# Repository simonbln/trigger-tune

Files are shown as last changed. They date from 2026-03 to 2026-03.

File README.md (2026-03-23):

# trigger-tune
Open-source audio player triggered by light beams

## Table of Contents
## Table of Contents
1. [Components](#components)
2. [Wiring Diagram](#wiring-diagram)
3. [Firmware Details](#firmware-details)
4. [DFPlayer Mini & SD Card Setup](#dfplayer-mini--sd-card-setup)
5. [LED Status Indicators](#led-status-indicators)
6. [How-To](#how-to)
    - [Breadboard Prototyping](#breadboard-prototyping)
    - [Firmware Setup](#firmware-setup)
    - [Important: USB Power Handling](#important-usb-power-handling)
    - [Build Prototype](#build-prototype)
7. [Support me](#support-me)
8. [Third-Party Code and License](#third-party-code-and-license)

## Components
- RP2040 (Zero)
- DFPlayer Mini
- USB Connector
- WS2812 (NeoPixel LED)
- Audio Jack
- Micro SD Card
- Perfboard (5x7cm)
- Connectors / Cables
- Enclosure / Box
- Lightbeam normally open NPN (if other is available, you have to adjust the code. Create a Issue if you have problems here)

## Wiring Diagram
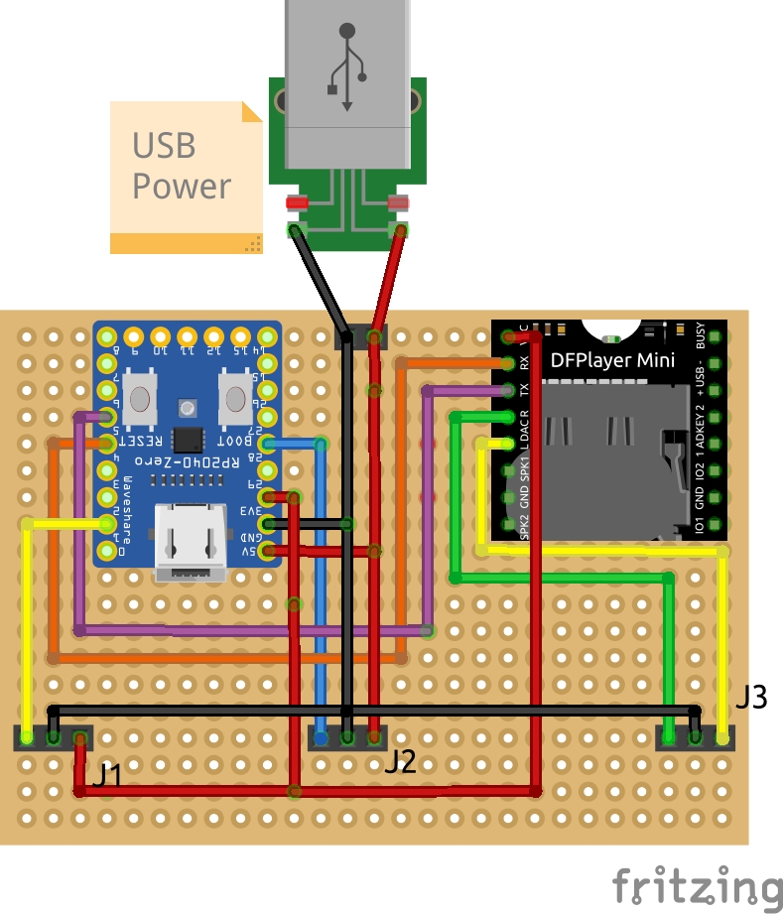
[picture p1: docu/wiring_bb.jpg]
Wiring Diagram

Figure 1: Wiring diagram on the perfboard

- **Connector J1** connects to the light barrier; the wiring will be split later into transmitter and receiver units. Additional light barriers can be wired in parallel here.
- **Connector J2** connects to the external WS2812 LED.
- **Connector J3** connects to the audio jack.

## Firmware Details
The firmware is written in **MicroPython** and utilizes a modified version of the [penguintutor/dfplayermini-pico](https://github.com/penguintutor/dfplayermini-pico) library.

The program continuously **polls the GPIO pin** connected to the light barrier. When triggered, it selects and plays a random MP3 file from the SD card. To ensure variety, the logic includes a mechanism that prevents the same track from being played twice in a row.

### Power Management & Optimization
While the RP2040 supports **Deep Sleep** with GPIO interrupts, this was not implemented. The **DFPlayer Mini** remains the primary power consumer in the circuit, making the power savings from MCU sleep modes negligible for this specific application.

## DFPlayer Mini & SD Card Setup
The DFPlayer Mini requires the SD card to be formatted to **FAT16 or FAT32**.

### SD Card Structure
The module requires a specific file naming convention to function reliably:
- **Folder naming:** Use a folder named `01` in the root directory.
- **File naming:** Files should be prefixed with a three-digit number (e.g., `001.mp3`).

## LED Status Indicators
The WS2812 LED (internal on PIN 16 and (optional) extenal on PIN 28) provides visual feedback on the system's state:

- **White:** System is initializing.
- **Green:** Ready and waiting for light beam trigger.
- **Blue:** Triggered / Playing audio. The LED stays blue for 1 second upon trigger; the song continues to play until the end unless a new trigger occurs during playback.
- **Red:** Error. No SD card detected or no MP3 files found in the specified folder.
- **Yellow:** Obstruction warning. The light beam is being triggered continuously (likely blocked or misaligned).

## How-To

### Breadboard Prototyping
For initial testing, it is recommended to build the circuit on a breadboard first as seen on the wiring diagram.

### Firmware Setup
1. Install **Thonny** IDE on your computer.
2. Flash the **MicroPython firmware** to the RP2040.  
   > **Firmware download:** [MicroPython for RP2040](https://micropython.org/download/rp2-pico/)
3. Copy all files from the `firmware` folder to the RP2040.

### Important: USB Power Handling
- **Do not** connect an external USB power source to the additional USB port while the RP2040 is connected to your computer via USB.
- Once the RP2040 is disconnected from the computer, the external USB port can be used to power all components. But for testing purpose you can use the USB Port of the RP2040.
- The external USB port will later be integrated into the enclosure.

### Build prototype
Solder the components and wires onto the perfboard as shown in Figure 1. Once the assembly is complete, perform an initial functional test before mounting the board into the enclosure.

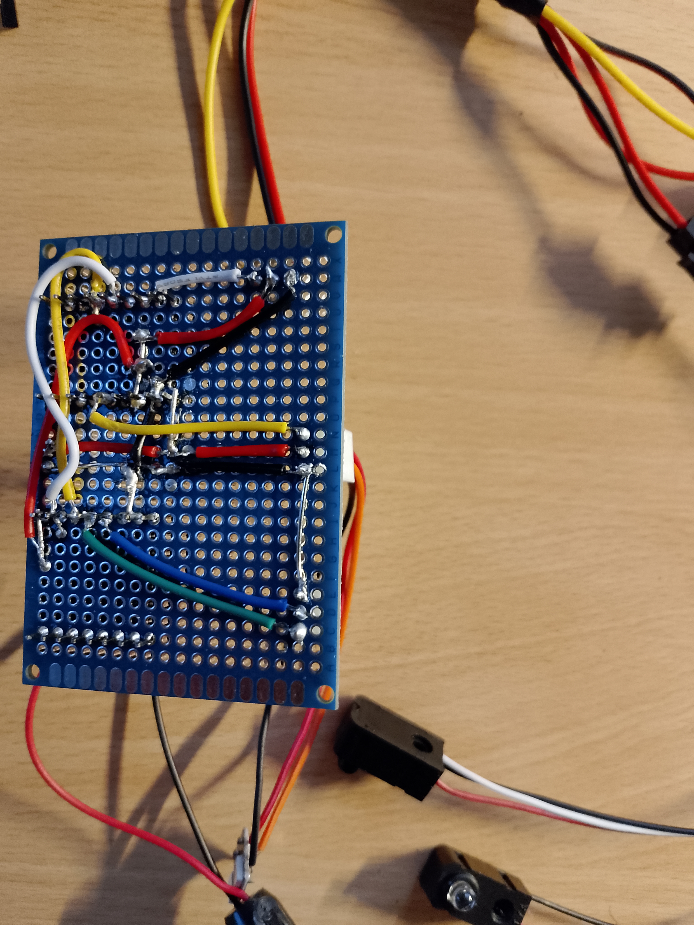
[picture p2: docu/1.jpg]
Soldering

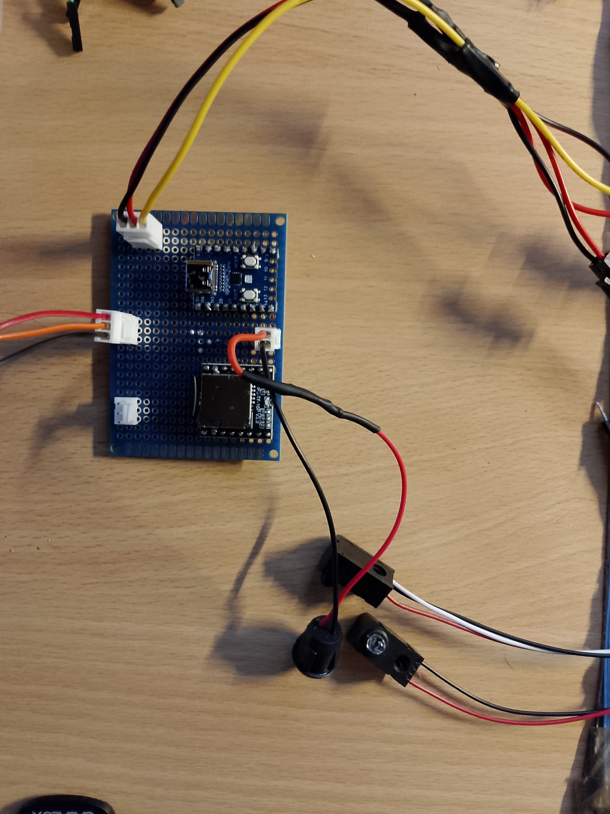
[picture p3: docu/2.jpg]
First Test


I decided to mount the circuit board to the lid. Since the enclosure is designed to be screwed down from the bottom, this prevents the mounting screws from interfering with the electronics. However, the board can also be mounted inside the box itself if preferred. I used rubber washers to dampen expected vibrations and minimize their transfer to the PCB.

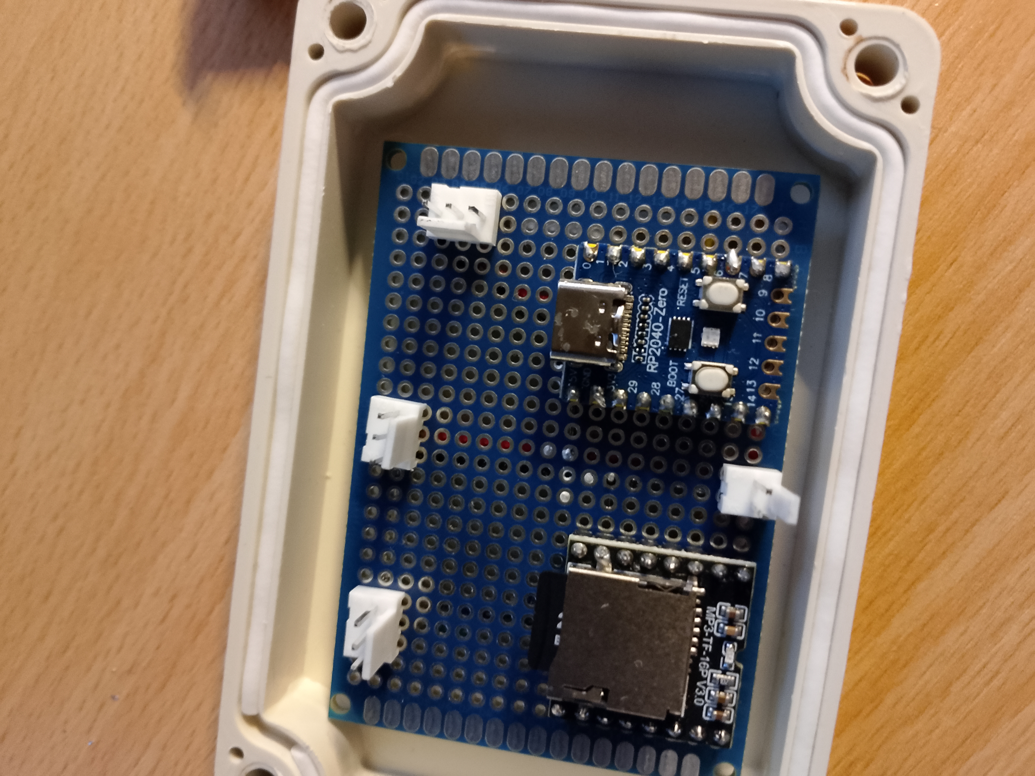
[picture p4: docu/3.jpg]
PCB in the lid


Drill the necessary holes for the cable glands and connectors, then insert them and secure with hot glue if necessary. The status LED was also routed through the lid for better visibility.

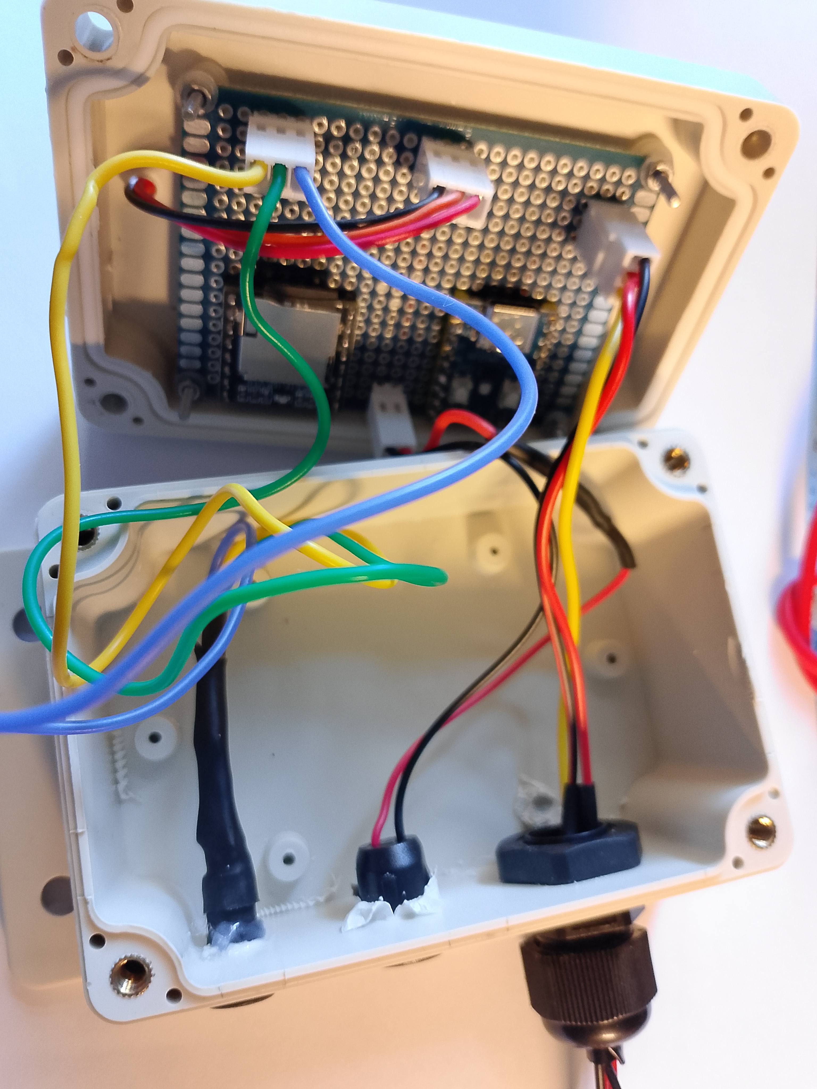
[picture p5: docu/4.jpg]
in the enclosure 1

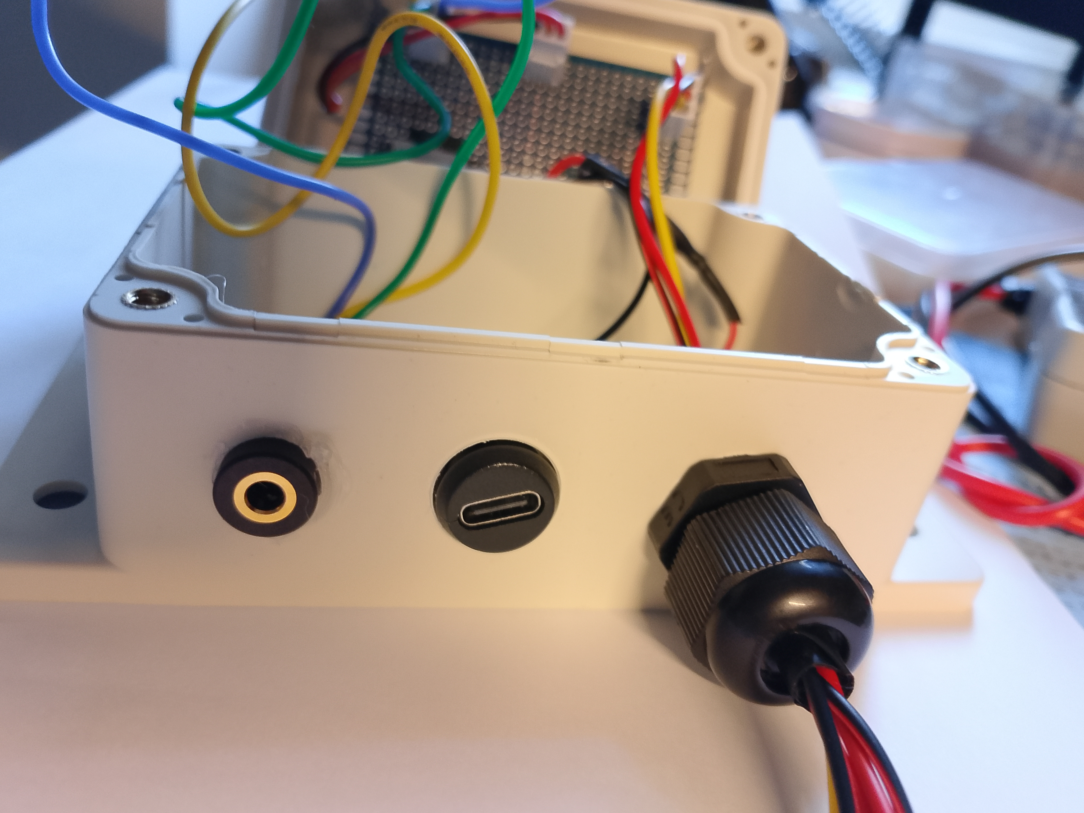
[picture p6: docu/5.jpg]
in the enclosure 2

PCB in the lid

**Note**: I am using two light barriers in this setup. Therefore, the wiring is split to connect both pairs (two transmitters and two receivers) in parallel.

## Support me
If you find this project helpful and would like to support my work, I would be very grateful for a contribution via GitHub Sponsors or in Bitcoin (BTC) / Litecoin (LTC). Every bit of support helps me to keep creating and sharing new projects. Thank you!

### LTC:
ltc1qx2yf4cndqr2zf3vfd7l2ywm5hylvhm0a8jrxry

LTC QR Code

### BTC: 
bc1q5yga8eluxk7cn4pc7k36lwee06mwt5gtre8nrm

BTC QR Code

### Bitcoin Cash
bitcoincash:qp4gapsmpt75nh7clp64dhae2myhl9h8tg2f77w652

Bitcoin_Cash QR Code

## Third-Party Code and License

This project contains modified code from the [penguintutor/dfplayermini-pico](https://github.com/penguintutor/dfplayermini-pico) repository.

*   **Original Author:** [@PenguinTutor](https://www.penguintutor.com)
*   **Original Repository License:** **GNU General Public License v3.0** (GPL-3.0) – see full text in the original repository's `LICENSE` file.
*   **Modifications by:** ([@simonbln](https://github.com/simonbln))
*   **Date of modifications:** March 2026
*   **Nature of modifications:**
    1.  Updated `command.to_bytes(1)` to `command.to_bytes(1, 'big')` for compatibility with newer Python versions.
    2.  Fixed the return value parsing for the reset command to correctly handle the module's response.

This modified version is distributed under the same license terms (GPL-3.0). The complete license text is included in this repository as `LICENSE`.

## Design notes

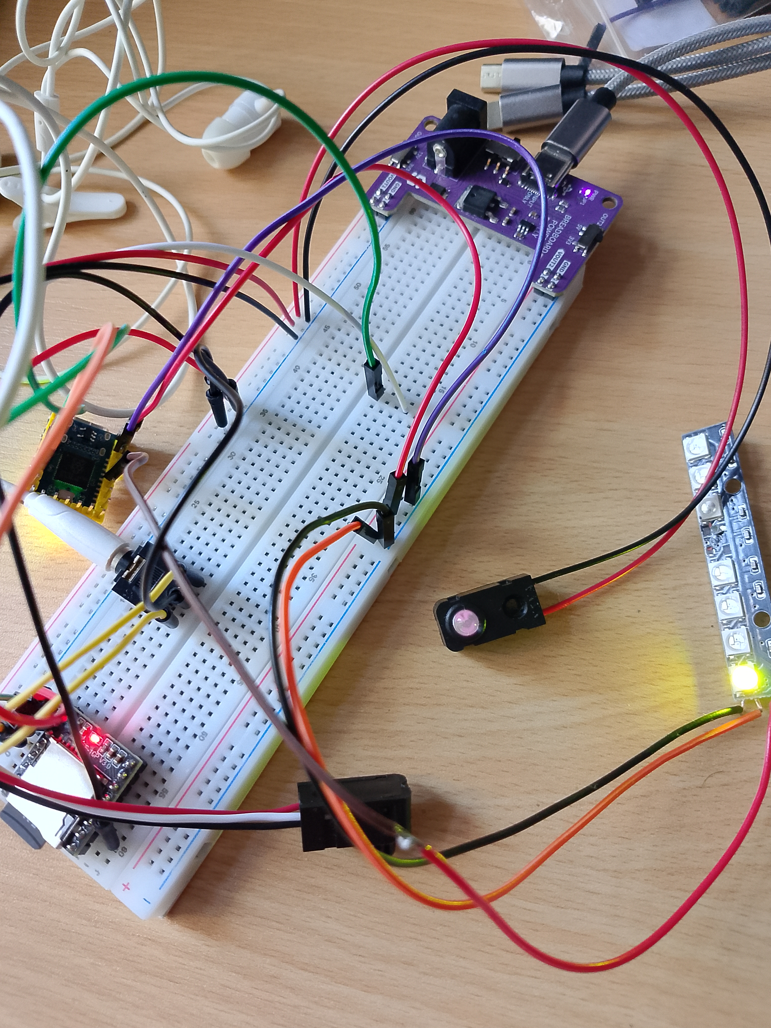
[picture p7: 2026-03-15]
docu/breadboard.jpg

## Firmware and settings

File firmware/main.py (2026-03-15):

from machine import Pin, UART, lightsleep
import neopixel
import time
import random
from dfplayermini import DFPlayerMini


print("start")


input_signal = Pin(2, Pin.IN, Pin.PULL_UP) 
pixel = neopixel.NeoPixel(Pin(16), 1)
pixel2 = neopixel.NeoPixel(Pin(28), 1)

class Colors:
    RED     = (50, 0, 0)
    GREEN   = (0, 50, 0)
    BLUE    = (0, 0, 50)
    YELLOW  = (50, 50, 0)
    CYAN    = (0, 50, 50)
    MAGENTA = (50, 0, 50)
    WHITE   = (50, 50, 50)
    OFF     = (0, 0, 0)

def set_pixel_color(color_rgb):
    pixel[0] = color_rgb
    pixel2[0]= color_rgb
    pixel.write()
    pixel2.write()
    
set_pixel_color(Colors.WHITE)

time.sleep(1)
player = DFPlayerMini(1,4,5)
time.sleep(1)
while True:
    print ("Reset")
    if player.reset() == True:
        print ("Reset: OK")
        break
    time.sleep(1)

time.sleep(1)
player.select_source('sdcard')

print ("Read Num files")
count_songs = player.query_num_files()
print (f"Num files {count_songs}")

print ("Read volume")
read_value = player.get_volume()
print (f"Volume {read_value}")

player.set_volume(30)

print ("Read volume")
read_value = player.get_volume()
print (f"Volume {read_value}")

ready_for_detection = True

last_song = 0

def play_random():
    global last_song
    if count_songs > 0:
        if count_songs == 1:
            # If only one song exists, just play it
            random_song = 1
        else:
            # Pick a song, but not the same as the last one
            random_song = last_song
            while random_song == last_song:
                random_song = random.randint(1, count_songs)
        
        # Update last_song for next time
        last_song = random_song
        
        print(f"Action: Playing random track {random_song}")
        player.play(random_song)
    else:
        print("Error: No songs found on SD card.")
        set_pixel_color(Colors.RED)

while True:
    if count_songs == 0:
        set_pixel_color(Colors.RED)
        time.sleep(2)
    elif input_signal.value() == 0:
        if ready_for_detection:
            ready_for_detection = False
            set_pixel_color(Colors.BLUE)
            play_random()
            time.sleep(1)
        else:
            set_pixel_color(Colors.YELLOW)
            time.sleep(0.5)
    else:
        ready_for_detection = True
        set_pixel_color(Colors.GREEN)
    time.sleep(0.05)

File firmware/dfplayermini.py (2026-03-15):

# A library to control the DFPlayer MP3 player
# Only partial implementation
# For more details of protocol see https://www.dfrobot.com/
# Created by Stewart Watkiss @PenguinTutor
# https://www.penguintutor.com 



# Original code by Stewart Watkiss @PenguinTutor
# https://www.penguintutor.com
# Source: https://github.com/penguintutor/dfplayermini-pico
# License: GNU General Public License v3.0 (GPL-3.0)
#
# Modified by simonbln - March 2026
# Changes:
# - command.to_bytes(1) -> command.to_bytes(1, 'big') for compatibility with newer Python versions
# - Fixed reset command return value parsing


from machine import UART, Pin
import time

class DFPlayerMini ():
    
    # how long to pause between read and write / subsequent reads
    sleep_time = 0.2
    debug = False
    
    sources = {
        'usb': 1,
        'sdcard': 2,
        'sd': 2,         # Allow sd as well as sd card
        'aux': 3,
        'sleep': 4,
        'flash': 5
        }
    
    def __init__ (self, uart_no, tx, rx):
        self.uart = UART(uart_no, baudrate=9600, tx=Pin(tx), rx=Pin(rx))
        self.uart.init(9600, bits=8, parity=None, stop=1)
        # Set to source when configured
        self.source = None
        # Keep track of if paused
        # Eg. allows resuming paused track when play is pressed
        self.paused = False
        
       
    # Simple check that looks for a standard 0x40 return code
    def check_return (self, byte_string):
        if byte_string[3] == 0x40:
            print ("Error receiving data")
            return False
        return True 
        
        
    # Send a byte string (bytes should alread be fully encoded)
    # then return the response
    def send_bytes (self, byte_string):
        sent_count = self.uart.write(byte_string)
        time.sleep(self.sleep_time)
        return self.read_reply()
        
    # Get a response - part of send_bytes, but also called seperately
    # where multiple replies are expected
    def read_reply (self):
        read_value = self.uart.read(10)
        if self.debug:
            if read_value == None:
                print ("None received")
                return None
            string_received = "".join([f"\\x{byte:02x}" for byte in read_value])
            print (f"Received {string_received}")
        return read_value
    
    
    def calc_checksum(self, data):
        # Data string
        sum = 0
        for byte in data:
            sum += byte
        #Convert to twos complement
        twos = (0xFFFF + 1 - sum)
        return twos
    
    def send_command (self, command, value=0, feedback=1):
        # Start = 7E
        # Version = FF
        # Len = 06
        # cmd
        # feedback = 1 or 0 (Whether response required) typically 1 for yes
        # para 1 (high data byte)
        # para 2 (low data byte)
        # checksum (from Version to para2) - 2 bytes
        # End = EF
        
        # Data without start, end or checksum
        data = b'\xFF\x06' + command.to_bytes(1, 'big') + feedback.to_bytes(1, 'big') + value.to_bytes(2, 'big')
        # Add checksum to data
        checksum = self.calc_checksum(data)
        data += checksum.to_bytes(2, 'big')
        # Add start and end bytes
        data_string = b'\x7E' + data + b'\xEF'
        string_sent = "".join([f"\\x{byte:02x}" for byte in data_string])
        if self.debug:
            print (f"Sending: {string_sent}")
        
        return self.send_bytes (data_string)
    
    def reset(self):
        self.paused = False
        #'reset' : b'\x7E\xFF\x06\x0C\x01\x00\x00\xFE\xEE\xEF'
        return_value = self.send_command(0x0C)
        #print(return_value)
        #print(len(return_value))
        #print (f"Return 1: {return_value}")
        # First return will be x41 with 0,0,0
        # Check for no return value or length of value is not correct
        if return_value == None or len(return_value) != 10:
            # If so just return without checking for a value
            return False
        # Reset wait 2 x sleep as sometimes needs to stabilise first
        time.sleep(self.sleep_time)
        time.sleep(self.sleep_time)
        # Next value should be x3f with 0,0,<response>
        return_value = self.read_reply()
        #print(return_value)
        #print(len(return_value))
        if len(return_value) == 1 and return_value[0] ==0x00:
            return True
        if return_value == None or len(return_value) != 10:
            # If so just return without checking for a value
            return False
        #print (f"Return 2: {return_value}")
        # Now check for a valid return value - lower data byte = [6]
        # 0 = Timeout
        #string_recv = "".join([f"\\x{byte:02x}" for byte in return_value])
        if return_value[3] != 0x3f:
            # Expecting 3f - if not then just return false
            return False
        # 2 = Cardinserted, 4 = CardOnline, 7 = USBInserted, 9 = USBOnline, 10 = CardUSBOnline
        if return_value[6] in (0x02, 0x04, 0x07, 0x09, 0x10):
            return True
        # Any other value return False
        return False


    # Get number of files on card / disk / flash
    # If source is default or None then uses current source
    def query_num_files(self, source=None):
        query_code = None
        # If no source set use current, otherwise return false
        if source == None:
            if self.source == None:
                return False
            source = self.source

        # Now source is set from parameter or using defult
        # Different from datasheet which says x47 - TF card, x48 = U-disk
        if source in ('sdcard', 'sd'):
            query_code = 0x48
        elif source == 'usb':
            query_code = 0x47
        elif source == 'flash':
            query_code = 0x49
            
        
        return_value = self.send_command(query_code)
        print (f"query_num_files {return_value}")
        # Check for no return value or length of value is not correct
        if return_value == None or len(return_value) != 10:
            # If so just return without checking for a value
            return False
        time.sleep(self.sleep_time)
        # Now check for a valid return value - lower data byte = [6]
        return_value = self.read_reply()
        # Now check for a valid return value - lower data byte = [6]
        # 0 = Timeout
        #string_recv = "".join([f"\\x{byte:02x}" for byte in return_value])
        if return_value[3] != query_code:
            # Expecting 3f - if not then just return false
            return False

        # Return value of lower byte + upper byte x (FF+1)
        eval_value = (return_value[5] * 256) + return_value[6]
        print (f"Eval {eval_value}")
        return eval_value
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

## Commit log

2026-03-13 first step
    [wiring.fzz]
2026-03-15 firmware, led and df mini player documentation
